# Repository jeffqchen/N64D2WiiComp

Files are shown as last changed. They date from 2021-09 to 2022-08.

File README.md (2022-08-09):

# N64D2WiiComp

A dongle for connecting a Wii component video cable to a N64Digital modded Nintendo 64

-----------

This adapter allows you to plug a Wii video cable into the AV Multi port into an Nintendo 64. The primary purpose is to allow the use of Wii component video cable on Nintendo 64 consoles modded with N64Digital and UltraHDMI in YUV mode.

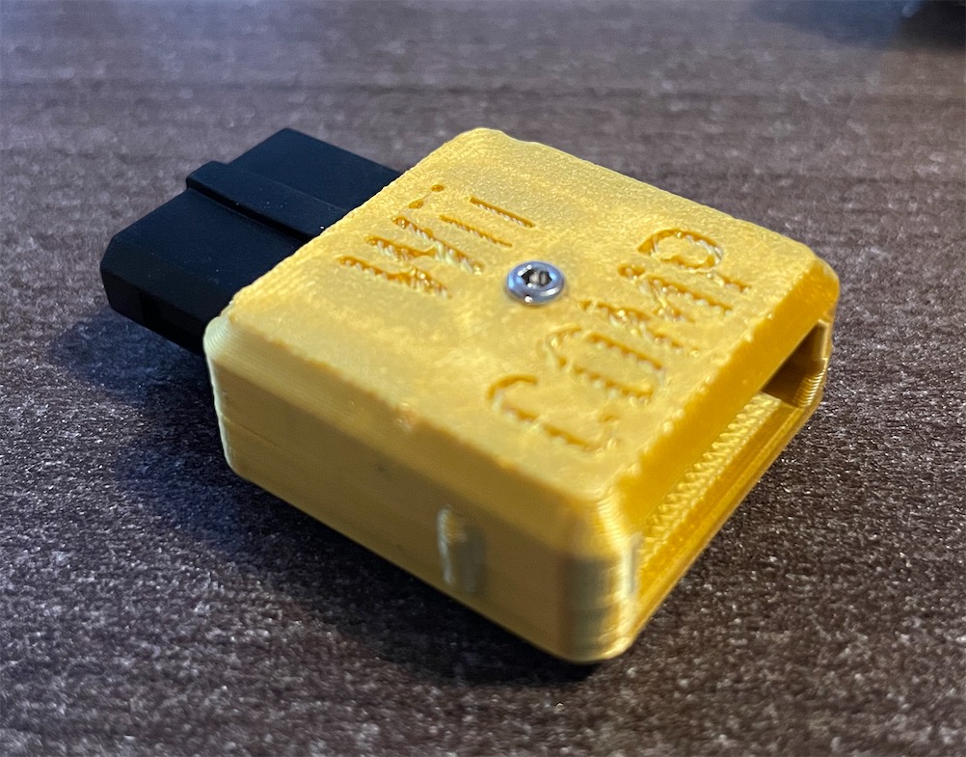
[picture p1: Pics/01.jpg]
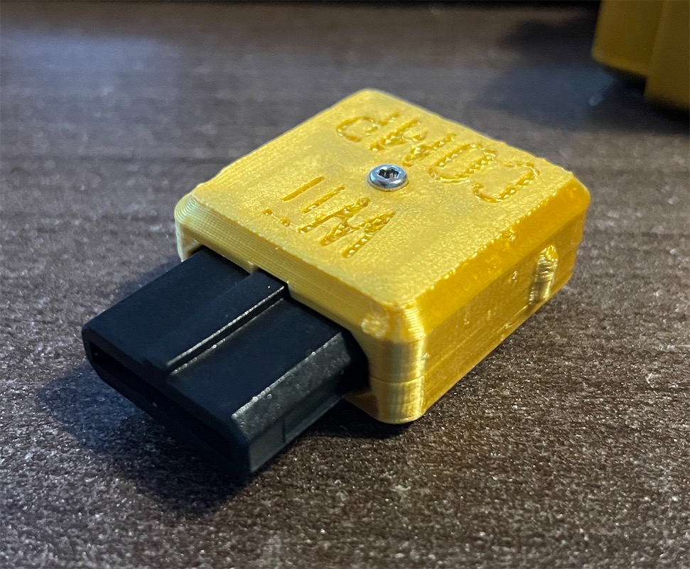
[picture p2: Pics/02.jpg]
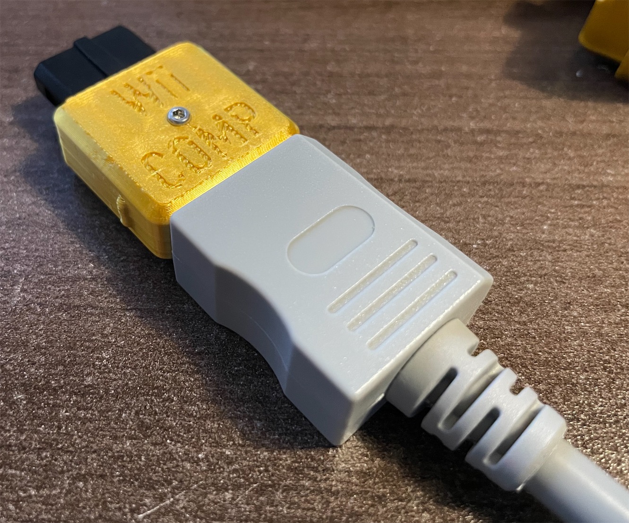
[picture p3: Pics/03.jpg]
  

## N64Digital Dual Output

You can use this adapter in combination with my mini to full HDMI dongle to achive dual output. Details:
https://www.thingiverse.com/thing:4924766

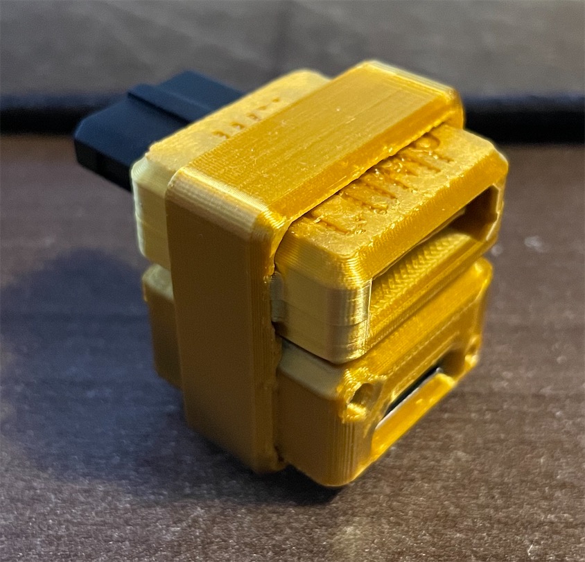
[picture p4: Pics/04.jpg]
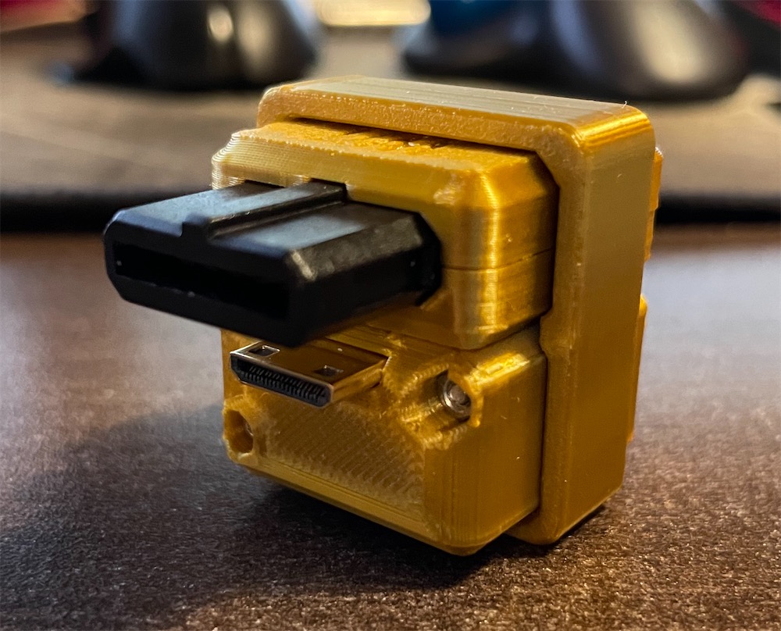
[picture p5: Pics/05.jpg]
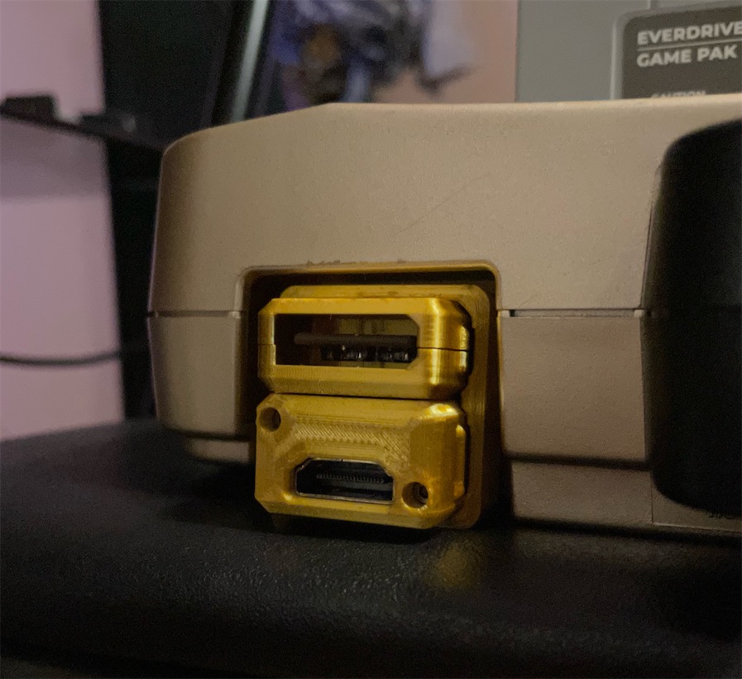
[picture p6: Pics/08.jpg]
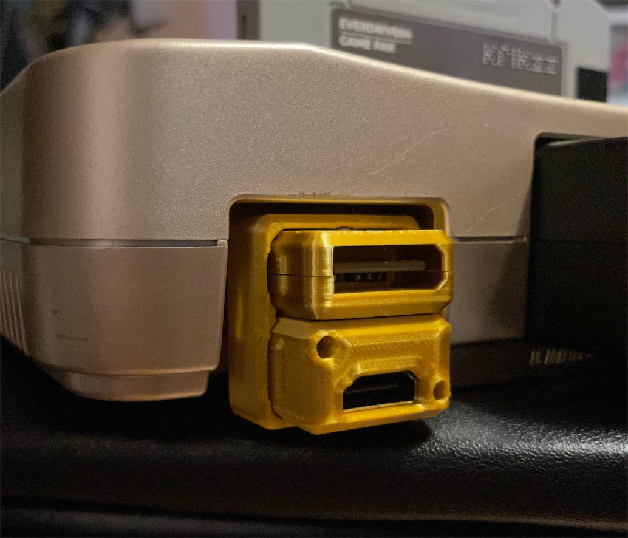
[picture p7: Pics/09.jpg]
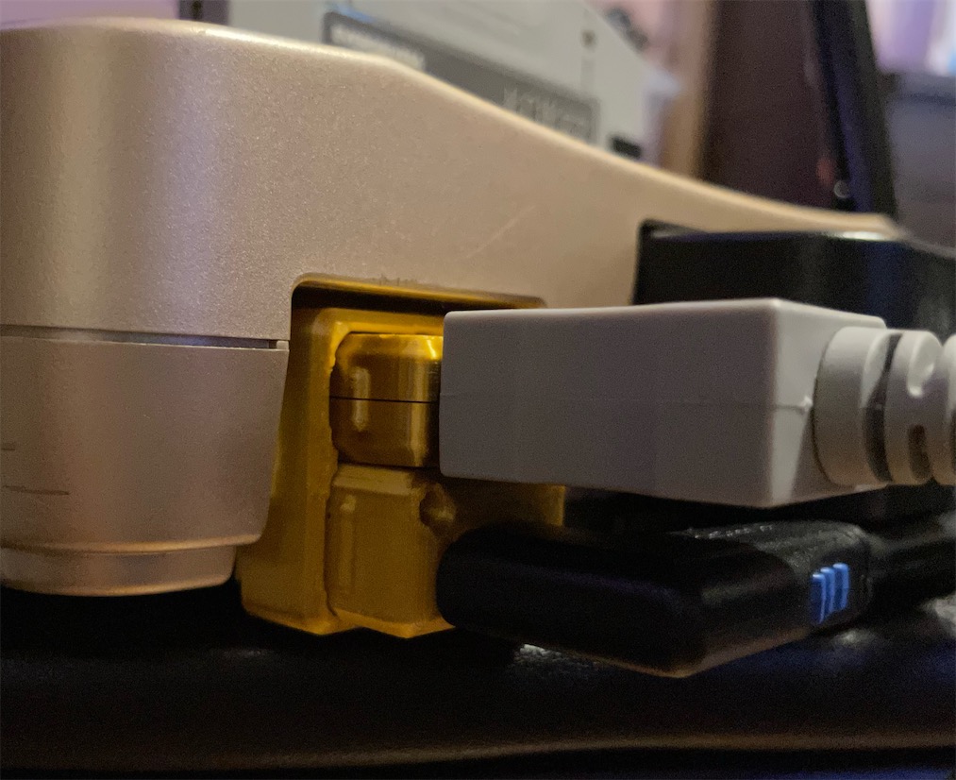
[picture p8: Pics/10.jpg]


## Variation

### [N64D2VGA](../../../SNES2VGA/tree/main/N64D2VGA)

Output analogue RGBS video and digital HDMI signal at the same time.

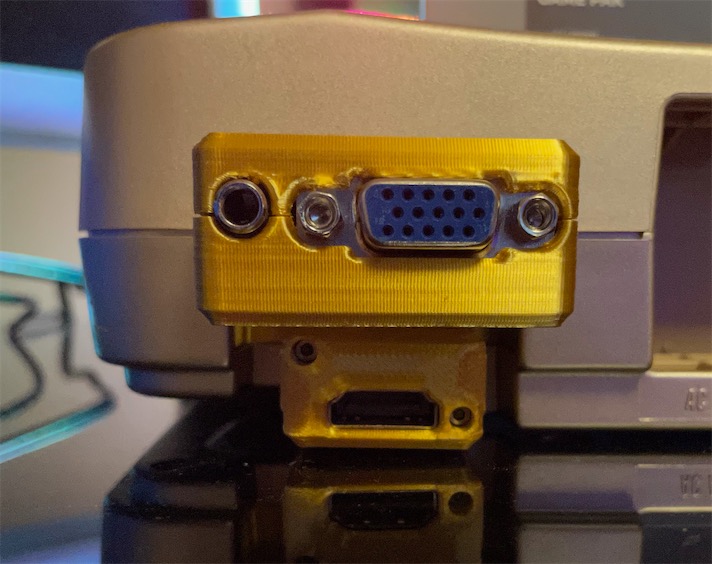
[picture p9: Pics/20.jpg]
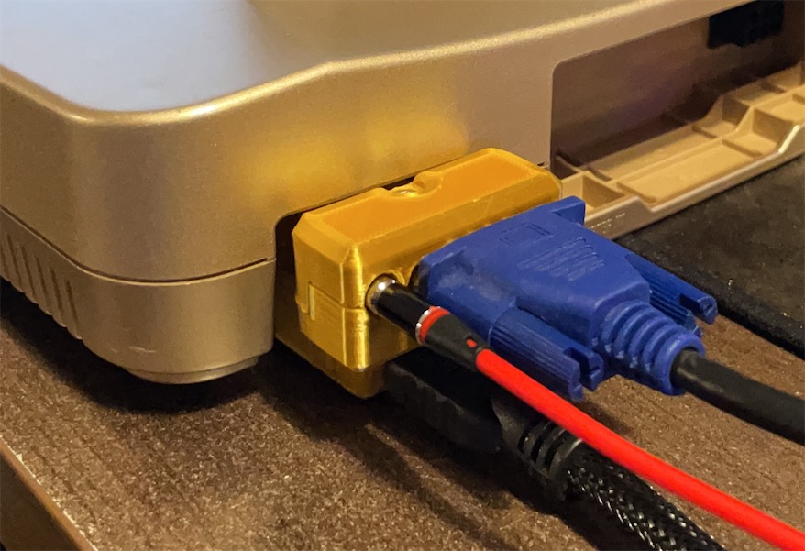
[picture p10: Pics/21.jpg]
 

-----------

## Part

- 3D Printed shell (also available on GitHub) - [Link](https://www.thingiverse.com/thing:4945082)

- PCB (also available on GitHub)
  - [Main](https://oshpark.com/shared_projects/ULsxf6av)
  - [Sub](https://oshpark.com/shared_projects/Sx7UN638)

- Nintendo Video Plug - [Link](https://github.com/jeffqchen/JeffParts/blob/main/Connectors/Nintendo%20AV%20Plug/info.md)

- M2x12mm (total length 13.8mm) screw and hex nut - [Link](https://github.com/jeffqchen/JeffParts/blob/main/Parts/M2%20M3%20Hex%20Screw%20%26%20Nut/info.md)

-----------

## 3D Print

Print the parts upside down for accurate port dimensions.
If you prefer better exterior look, print upright with a raft to minimize height error.

The ring is for joining this adapter together with the mini HDMI to full HDMI adapter for the N64Digital, for better mechanical rigidity. It should also help even if the HDMI adapter is not in place, so the adapter can't sag and damage anything.
https://www.thingiverse.com/thing:4924766

-----------
## Before Assembly

File the Wii end of the PCB that goes into the component cable, so it has a chamfer on both the top and bottom side of the board. This is to ensure it doesn't damage or destroy the contacts inside your Wii component cable.

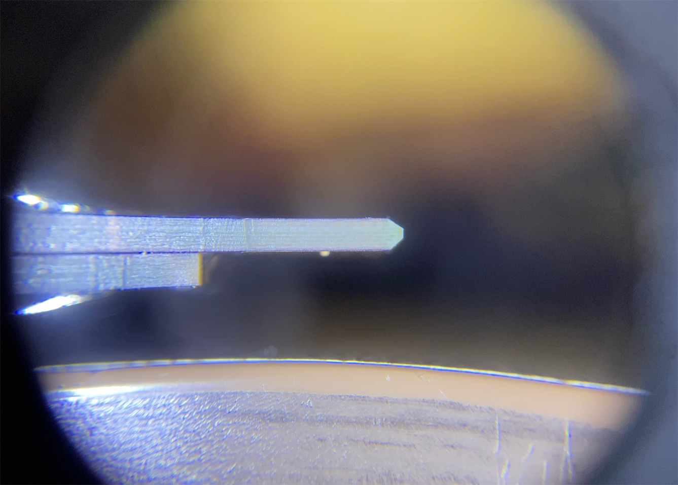
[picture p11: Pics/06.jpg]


Please note the white line near the end of the golden fingers. It is recommended you file the edge all the way down to the line at 45 degrees.

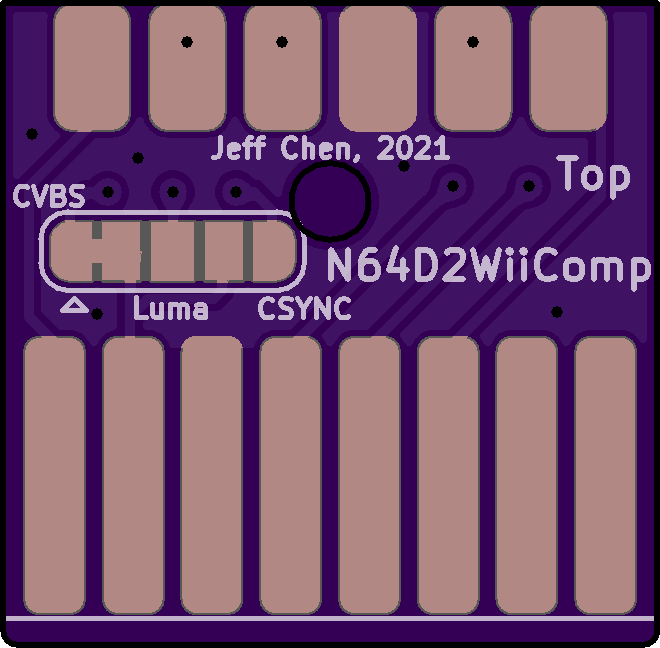
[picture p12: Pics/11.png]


-----------

## Assembly

Solder the two PCBs toghether. Note the "This should NOT be visible" silkscreen print and obey. Then solder the SNES header onto the PCB assembly. Note the "Top" print. This indicates the way the notch on the plug should face.

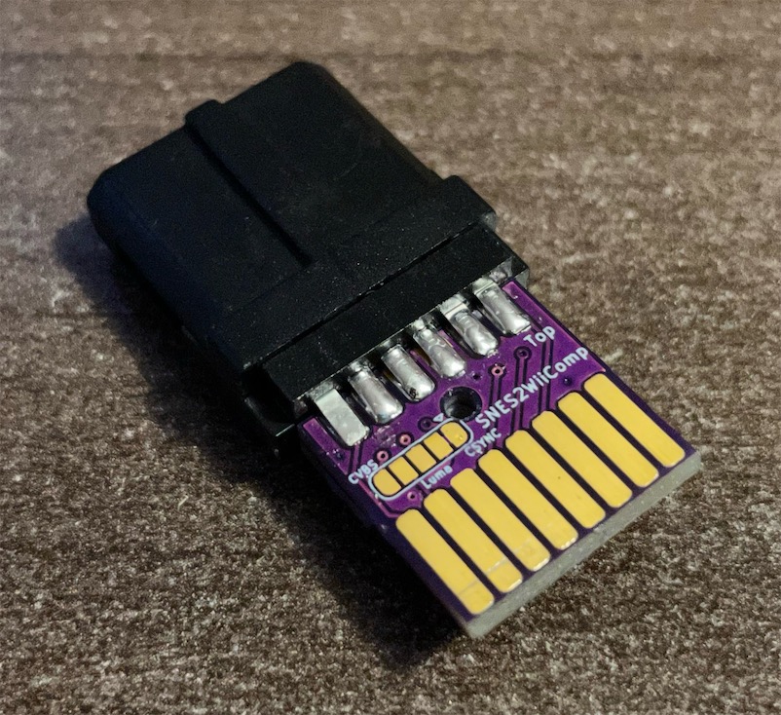
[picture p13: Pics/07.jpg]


Place the soldered assembly into the printed shell and screw them together.

----------
## Misc

The composite signal is also connected by default. You can use a composite video cable for the Wii for composite video output.

It is possible to sever the default jumper on the PCB and then bridge Luma or CSync for connecting an RGBs cable. However there will be extra components required for such cable to function properly.

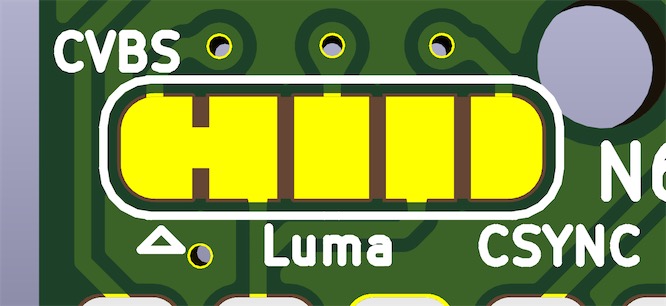
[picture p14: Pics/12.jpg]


----------
## Special Thanks
Rainy Day Retro, the one who requested this to be made
- https://twitter.com/rainydayretro

citrus3000psi, the super famous creator of many console mods
- https://twitter.com/citrus3000psi
- https://www.black-dog.tech

qwertymodo
- https://twitter.com/qwertymodo

Shank
- https://twitter.com/ShankMods

----------
Shield: [][cc-by-sa]

This work is licensed under a
[Creative Commons Attribution-ShareAlike 4.0 International License][cc-by-sa].

[][cc-by-sa]

[cc-by-sa]: http://creativecommons.org/licenses/by-sa/4.0/
[cc-by-sa-image]: https://licensebuttons.net/l/by-sa/4.0/88x31.png
[cc-by-sa-shield]: https://img.shields.io/badge/License-CC%20BY--SA%204.0-lightgrey.svg

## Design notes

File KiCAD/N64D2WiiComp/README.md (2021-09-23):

# N64D2WiiComp
A dongle for connecting a Wii component video cable to a N64Digital modded Nintendo 64

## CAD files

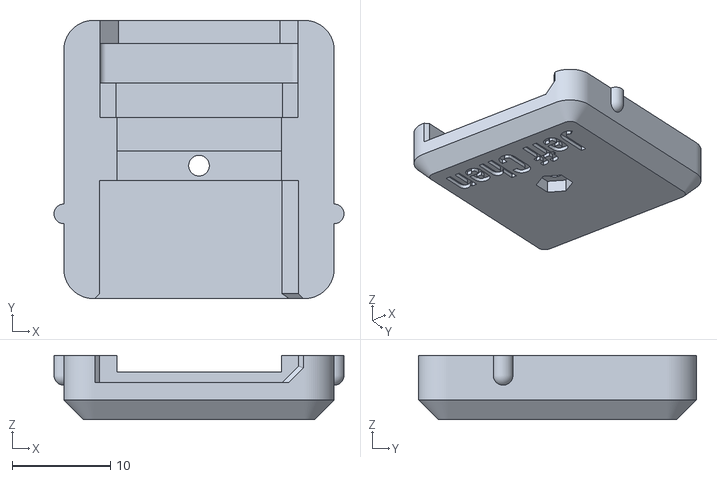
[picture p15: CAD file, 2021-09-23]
3D Print/Shroud Bottom.stl
29.5 x 28.2 x 6.52

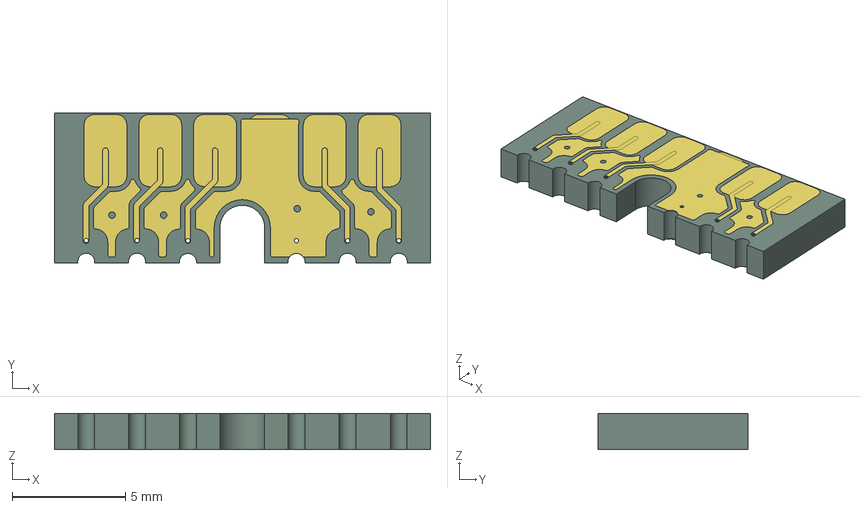
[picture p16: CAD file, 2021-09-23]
KiCAD/N64D2WiiComp/WiiComp_Sub/WiiComp_Sub-WiiComp_Sub_stepup.step
16.6 x 6.61 x 1.70 mm
Local_CS_7a3d
Pcb_7a3d
PCB_Sketch_7a3d
topTracks_7a3d
botTracks_7a3d

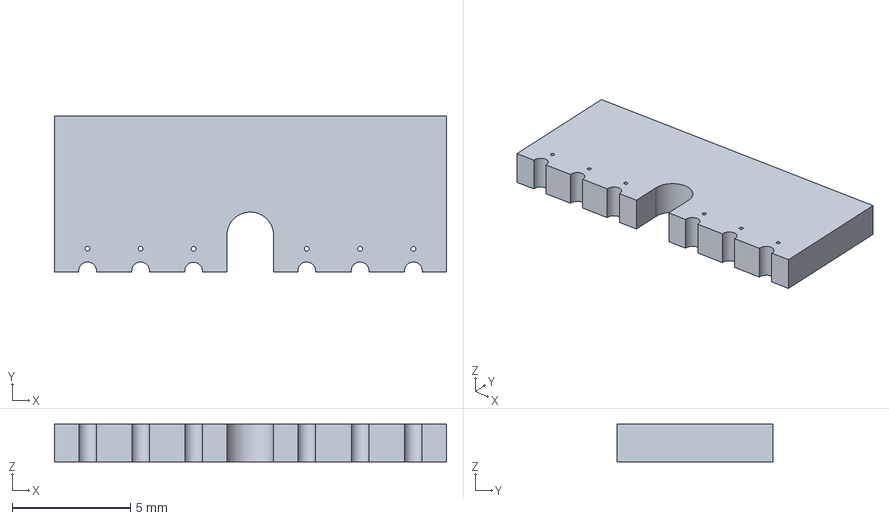
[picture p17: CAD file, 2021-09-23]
KiCAD/N64D2WiiComp/WiiComp_Sub/WiiComp_Sub.step
16.6 x 6.61 x 1.60 mm

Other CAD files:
3D Print/Shroud Top.stl

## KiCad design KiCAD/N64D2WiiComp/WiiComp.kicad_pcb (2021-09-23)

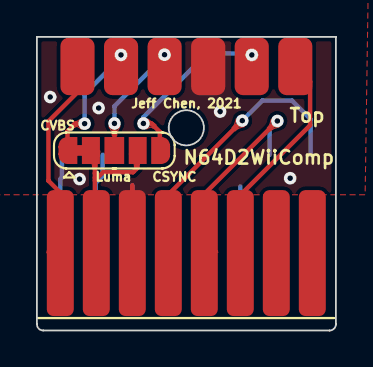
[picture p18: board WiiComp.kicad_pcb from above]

Board: 2 copper layers, 16.6 x 16.3 mm, 4 parts (0 on the bottom side), 11 nets.

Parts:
JP1: CVBS/Luma Jumper; SolderJumper-3_P1.3mm_Bridged12_RoundedPad1.0x1.5mm
JP2: CSync/Luma Jumper; SolderJumper-3_P1.3mm_Open_RoundedPad1.0x1.5mm
P1: AVMulti_Main; AV_Multi_Main
P2: Wii_AV_Multi

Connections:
/+5V: P1.10, P2.4
/Audio_L: P1.11, P2.1
/Audio_R: P1.12, P2.2
/CSync: JP2.1, P1.3
/CVBS: JP1.1, P1.9
/Luma: JP1.3, JP2.3, P1.7
/Pb: P1.4, P2.9
/Pr: P1.1, P2.11
/Sync: JP1.2, JP2.2, P2.3
/Y: P1.2, P2.7
GND: P1.5, P1.6, P2.5, P2.6, P2.12

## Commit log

2021-09-23 Initial upload
    [Shroud Bottom.stl, Shroud Top.stl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]
2021-10-24 Update PCB
    [WiiComp-B_Mask.gbr, WiiComp-B_Paste.gbr, WiiComp-B_SilkS.gbr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]

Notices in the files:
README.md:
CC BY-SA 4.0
